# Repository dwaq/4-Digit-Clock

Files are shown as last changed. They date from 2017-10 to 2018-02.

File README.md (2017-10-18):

# 4-Digit-Clock
CNC fab-able clock based on the ATMEGA328P

## Hardware
Schematic and Board files created in Autodesk EAGLE 8.

## Software
Software written in Arduino.

Past software was written in C, but had a fatal bug. It was deleted in [commit 8a6b835](https://github.com/dwaq/4-Digit-Clock/commit/8a6b8354e79f4e0a9605a9b12ea75d16f3cf73cc).

## License
This work is licensed under a Creative Commons Attribution 3.0 Unported License.

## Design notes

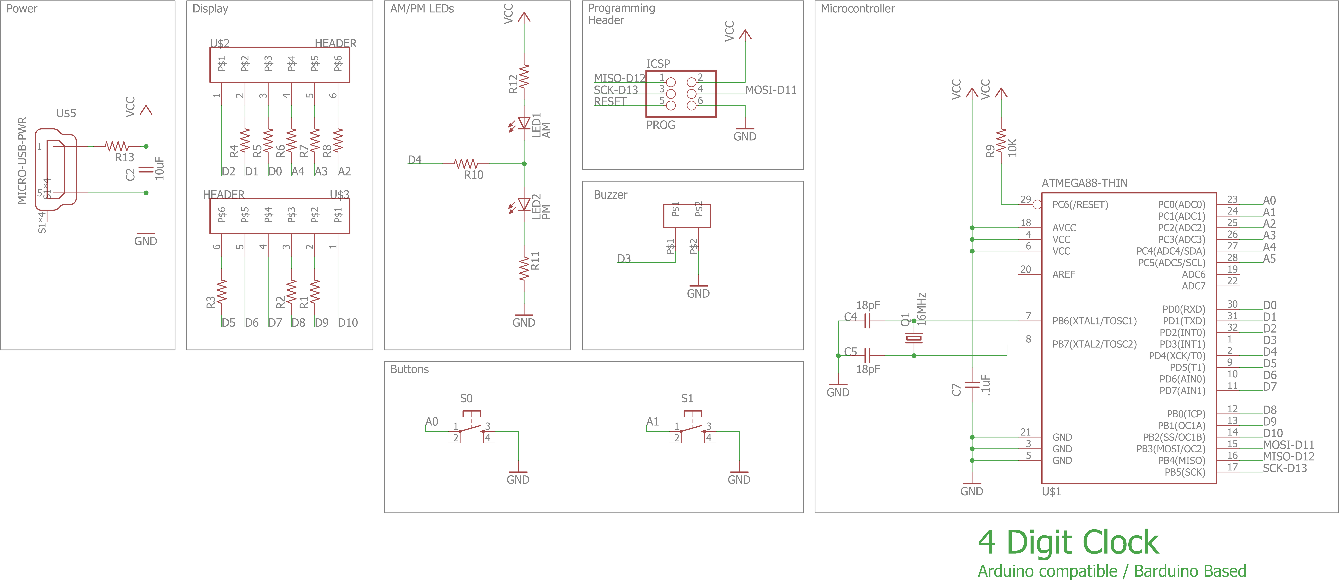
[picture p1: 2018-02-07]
schematic.png

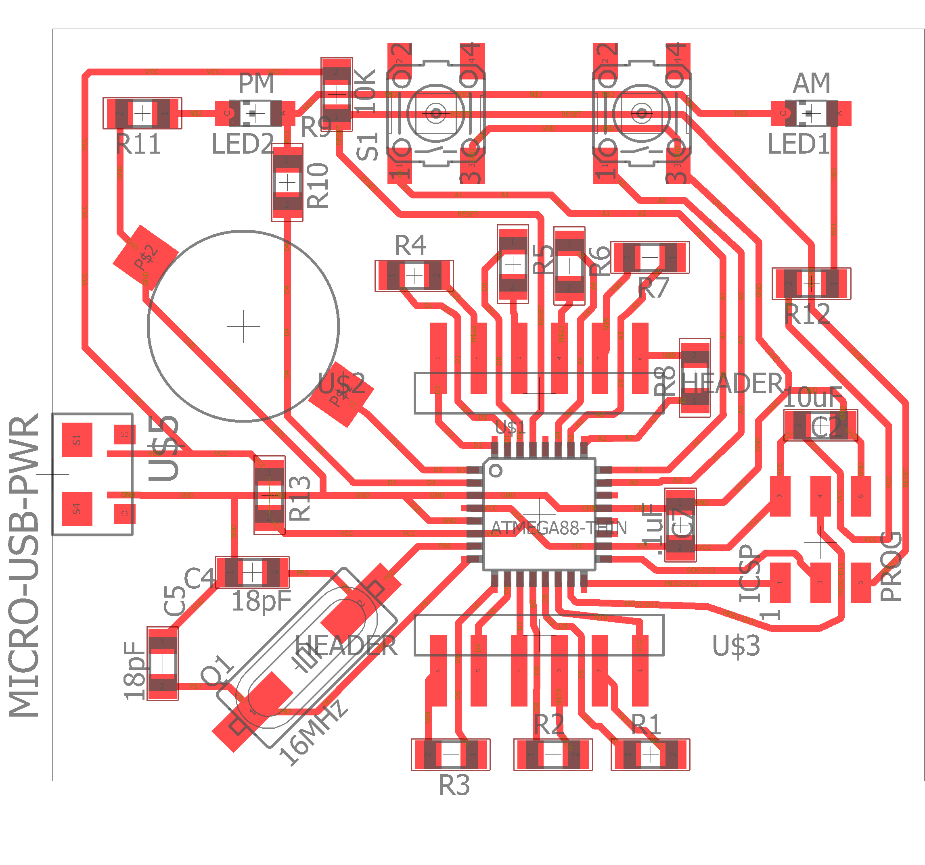
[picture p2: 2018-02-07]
layout.png

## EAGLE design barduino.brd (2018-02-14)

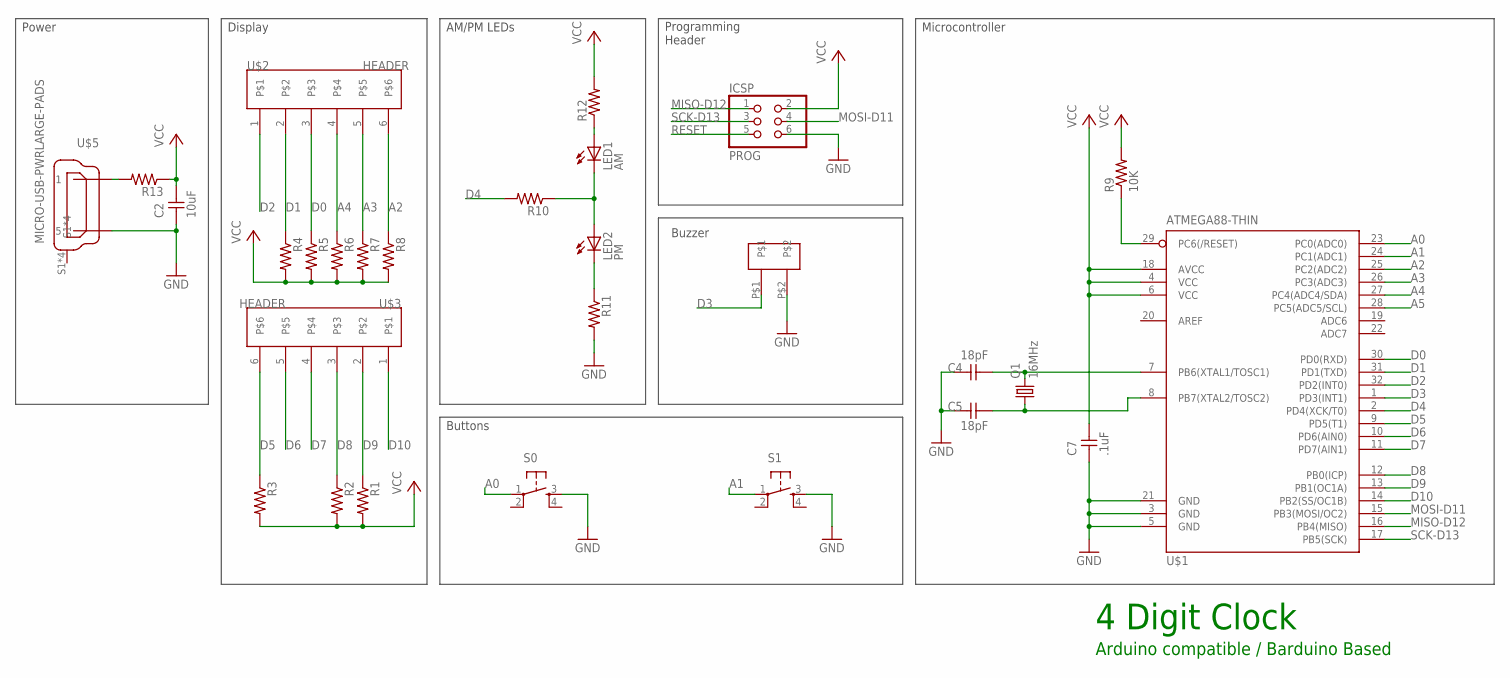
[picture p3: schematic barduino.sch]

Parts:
C2: 10uF; 1206
C4, C5: 18pF; 1206
C7: .1uF; 1206
ICSP: PROG; 2X03SMD
LED1: AM; CHIPLED_1206
LED2: PM; CHIPLED_1206
Q1: 16MHz; HC49UP
R1, R2, R3, R4, R5, R6, R7, R8, R10, R11, R12, R13: R-US_R1206; R1206
R9: 10K; 1206
S0, S1: 6MM_SWITCH6MM_SWITCH; 6MM_SWITCH
U$1: ATMEGA88-THIN; TQFP32-08THIN
U$2, U$3: HEADER
U$4: BUZZERLARGE-PADS; CD-1206-SMT-LRG
U$5: MICRO-USB-PWRLARGE-PADS; DX4R005HJ5-PWR-PADS

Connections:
A0: S0.1, U$1.23 (PC0(ADC0))
A1: S1.1, U$1.24 (PC1(ADC1))
A2: R8.1, U$1.25 (PC2(ADC2)), U$2.6
A3: R7.1, U$1.26 (PC3(ADC3)), U$2.5
A4: R6.1, U$1.27 (PC4(ADC4/SDA)), U$2.4
A5: U$1.28 (PC5(ADC5/SCL))
D0: R5.1, U$1.30 (PD0(RXD)), U$2.3
D1: R4.1, U$1.31 (PD1(TXD)), U$2.2
D2: U$1.32 (PD2(INT0)), U$2.1
D3: U$1.1 (PD3(INT1)), U$4.P$1
D4: R10.2, U$1.2 (PD4(XCK/T0))
D5: R3.1, U$1.9 (PD5(T1)), U$3.6
D6: U$1.10 (PD6(AIN0)), U$3.5
D7: U$1.11 (PD7(AIN1)), U$3.4
D8: R2.1, U$1.12 (PB0(ICP)), U$3.3
D9: R1.1, U$1.13 (PB1(OC1A)), U$3.2
D10: U$1.14 (PB2(SS/OC1B)), U$3.1
GND: C2.1, C4.1, C5.1, C7.1, ICSP.6, R11.2, S0.3 (S), S1.3 (S), U$1.3 (GND), U$1.5 (GND), U$1.21 (GND), U$4.P$2, U$5.GND (5)
MISO-D12: ICSP.1, U$1.16 (PB4(MISO))
MOSI-D11: ICSP.4, U$1.15 (PB3(MOSI/OC2))
unnamed: LED1.A, R12.1
unnamed: LED2.C, R11.1
unnamed: LED1.C, LED2.A, R10.1
PB6: C4.2, Q1.2, U$1.7 (PB6(XTAL1/TOSC1))
PB7: C5.2, Q1.1, U$1.8 (PB7(XTAL2/TOSC2))
RESET: ICSP.5, R9.1, U$1.29 (PC6(/RESET))
SCK-D13: ICSP.3, U$1.17 (PB5(SCK))
VCC: C2.2, C7.2, ICSP.2, R1.2, R2.2, R3.2, R4.2, R5.2, R6.2, R7.2, R8.2, R9.2, R12.2, R13.1, R13.2, U$1.4 (VCC), U$1.6 (VCC), U$1.18 (AVCC), U$5.VBUS (1)

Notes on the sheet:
Power
Buttons
Programming Header
4 Digit Clock
Arduino compatible / Barduino Based
Buzzer
Display
AM/PM LEDs
Microcontroller

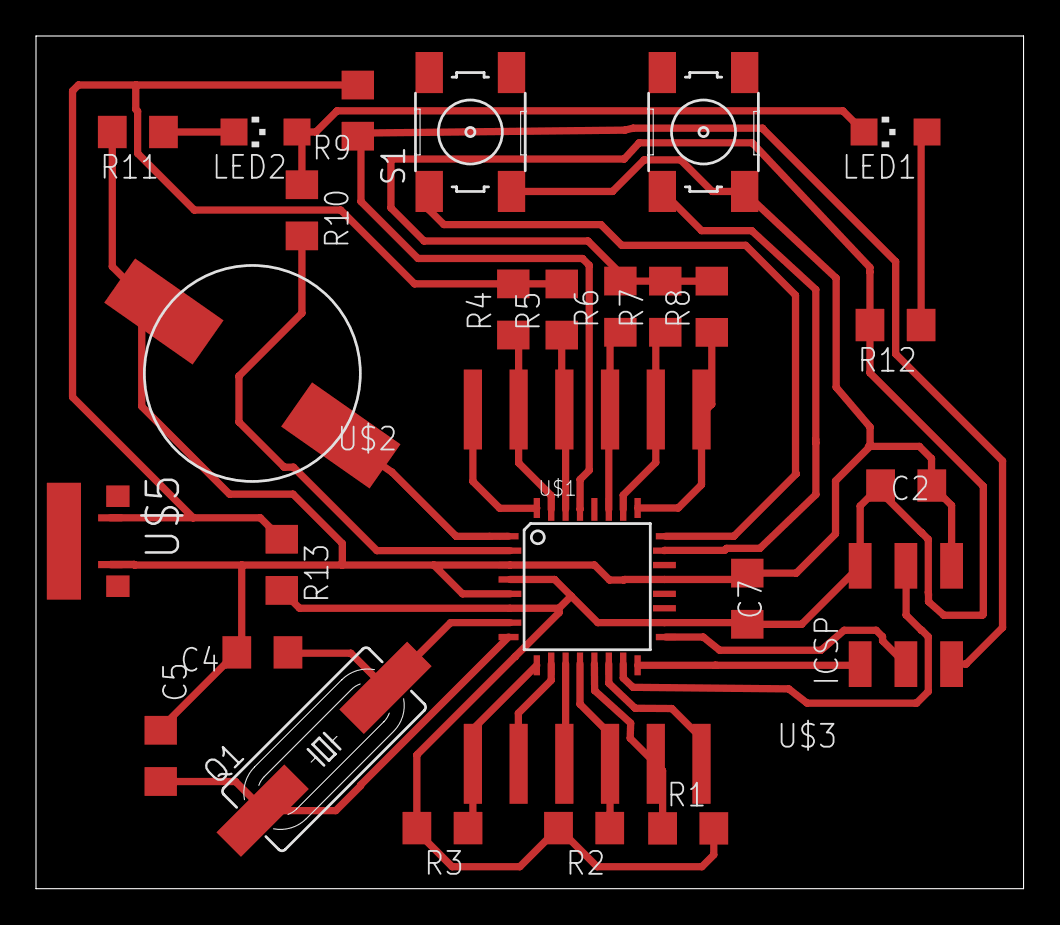
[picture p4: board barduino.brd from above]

Board: 2 copper layers, 54.9 x 47.4 mm, 28 parts (0 on the bottom side), 27 nets.

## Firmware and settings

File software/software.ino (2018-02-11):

#include "main.h"
#include "display.h"
#include <TimerOne.h>

// time
struct TimeType {
  int sec;
  int min;
  int hr;
  // differentiate between AM and PM
  // 0 = AM // 1 = PM
  int time_of_day;
  // decimal point
  int dp;
  // switch between HH:MM and MM:SS
  int display;
};
TimeType time;

// alarm
struct AlarmType {
  // alarm on or off
  int enabled;
  // alarm time
  int hr;
  int min;
  // AM/PM for alarm
  // 0 = AM // 1 = PM
  int time_of_day;
  // alarm going off
  int play;
};
AlarmType alarm;

// default to clock display mode
int settings_mode = CLOCK;

// hourly chime on or off
int hr_chime_enabled = 1;

// capture only 1 button press (kinda like debouncing)
int buttonBlockA0 = 0;
int buttonBlockA1 = 0;

void setup() {
  // set up default time values
  time.sec = 0;
  time.min = 0;
  time.hr = 12;
  time.time_of_day = 1;
  time.dp = 0;
  time.display = 1;

  // set up default alarm values
  alarm.hr = 12;
  alarm.min = 0;
  alarm.time_of_day = 1;
  alarm.enabled = 0;
  alarm.play = 0;

  // set display pins to outputs
  displaySetup();

  // set LED pin to output
  ledSetup();

  // start at PM
  ledPm();

  // set button pins to interrupt-enabled inputs
  buttonsSetup();

  // setup timer for 1 second tick
  Timer1.initialize(1000000);
  Timer1.attachInterrupt(increaseSecond);
}

void loop() {
  // displayDigits in loop so they keep updating

  // default clock display mode
  if (settings_mode == CLOCK)
  {
    // HH:MM
    if(time.display)
    {
      // don't display leading 0 for hours
      // display 2:00 instead of 02:00
      if (time.hr < 10)
      {
        displayDigits(BLANK, time.hr%10, time.dp, time.min/10, time.min%10);
      }
      else
      {
        displayDigits(time.hr/10, time.hr%10, time.dp, time.min/10, time.min%10);
      }
    }
    // MM:SS
    else
    {
      displayDigits(time.min/10, time.min%10, time.dp, time.sec/10, time.sec%10);
    }
  }
  else if (settings_mode == SET_HR)
  {
    displayDigits(SET_HR, BLANK, BLANK, time.hr/10, time.hr%10);
  }
  else if (settings_mode == SET_MIN)
  {
    displayDigits(SET_MIN, BLANK, BLANK, time.min/10, time.min%10);
  }
  else if (settings_mode == SET_CHIME)
  {
    // on
    if (hr_chime_enabled)
    {
      displayDigits(SET_CHIME, BLANK, BLANK, 0, N);
    }
    // off
    else
    {
      displayDigits(SET_CHIME, 0, BLANK, 0xF, 0xF);
    }
  }
  else if (settings_mode == SET_ALARM)
  {
    // on
    if (alarm.enabled)
    {
      displayDigits(SET_ALARM, BLANK, BLANK, 0, N);
    }
    // off
    else
    {
      displayDigits(SET_ALARM, 0, BLANK, 0xF, 0xF);
    }
  }
  else if (settings_mode == SET_ALARM_HR)
  {
    displayDigits(SET_ALARM_HR, BLANK, BLANK, alarm.hr/10, alarm.hr%10);
    
    // change LED to match alarm
    if (alarm.time_of_day)
    {
      ledPm();
    }
    else{
      ledAm();
    }
  }
  else if (settings_mode == SET_ALARM_MIN)
  {
    displayDigits(SET_ALARM_MIN, BLANK, BLANK, alarm.min/10, alarm.min%10);
    
    // change LED to match time
    // (back to normal behavior after setting LED to alarm time of day in last state)
    if (time.time_of_day)
    {
      ledPm();
    }
    else{
      ledAm();
    }
  }

  // S1 button pressed in interrupt
  if (buttonBlockA0 == 10)
  {
    // reduce so it doesn't get caught in a loop
    buttonBlockA0--;
    // S1 handler
    buttonS1();
  }

  // S2 button pressed in interrupt
  if (buttonBlockA1 == 10)
  {
    // reduce so it doesn't get caught in a loop
    buttonBlockA1--;
    // S2 handler
    buttonS2();
  }
}

// correctly move through settings states
void nextSettingState(void)
{
  // if you've turned alarm off, dont't set it, go back to clock display
  if ((settings_mode == SET_ALARM) & (alarm.enabled == 0))
  {
    settings_mode = CLOCK;
  }
  // last setting, go back to clock display
  else if (settings_mode == SET_ALARM_MIN)
  {
    settings_mode = CLOCK;
  }
  // else just go to next state
  else{
    settings_mode++;
  }

  // stop counting time when you're trying to set it
  if (settings_mode == SET_HR)
  {
    // disable timer counter
    Timer1.stop();

    // also reset seconds for good measure
    time.sec = 0;
  }
  // start counting after you've set the time
  else if (settings_mode == SET_CHIME)
  {
    // restart timer counter
    Timer1.restart();
  }
}

// Hack to get pin change interrupts on analog pins
// http://www.geertlangereis.nl/Electronics/Pin_Change_Interrupts/PinChange_en.html
void buttonsSetup()
{
  // set button pins as inputs with internal pull-ups enabled
  pinMode(A0, INPUT);
  digitalWrite(A0, HIGH);
  pinMode(A1, INPUT);
  digitalWrite(A1, HIGH);

  // switch interrupts off while messing with their settings
  cli();
  // Enable PCINT1 interrupt
  PCICR =0x02;
  PCMSK1 = 0b00000111;
  // turn interrupts back on
  sei();
}

// Interrupt service routine for every analog pin change
// A0, A1, A2, A3, A4, A5
ISR(PCINT1_vect) {
  // press A0
  if (digitalRead(A0)==0 && buttonBlockA0==0)
  {
    // pressing button stops alarm
    if (alarm.play == 1)
    {
      noTone(3);
      alarm.play = 0;

      // set to a smaller value so bouncing dones't trigger interrupt
      buttonBlockA0 = 9;
    }
    // else do normal behavior
    else {
      // set to 10
      buttonBlockA0 = 10;
      
      // will handle press in main loop
    }
  }
  // release A0
  if (digitalRead(A0)==1)
  {
    // count down after releasing
    if (buttonBlockA0 > 0)
    {
      buttonBlockA0--;
    }
  }

  // press A1
  if (digitalRead(A1)==0 && buttonBlockA1==0)
  {
    // pressing button stops alarm
    if (alarm.play == 1)
    {
      noTone(3);
      alarm.play = 0;

      // set to a smaller value so bouncing doesn't trigger interrupt
      buttonBlockA1 = 9;
    }
    // else do normal behavior
    else
    {
      // set to 10
      buttonBlockA1 = 10;
      
      // will handle press in main loop
    }
  }
  // release A1
  if (digitalRead(A1)==1)
  {
    // count down after releasing
    if (buttonBlockA1 > 0)
    {
      buttonBlockA1--;
    }
  }
}

void buttonBuzzer()
{
  // send 133 frequency tone for 70 ms to pin 3
  tone(3, 133, 70);
  // wait 70ms for tone to finish
  delay(70);
  // in case it didn't finish, kill it
  noTone(3);
}

void buttonS1()
{
  // play tone
  buttonBuzzer();
  
  // go to next settings state
  nextSettingState();
}

void buttonS2()
{
  // play tone
  buttonBuzzer();
  
  // need to be in clock display mode to change these settings
  if (settings_mode == CLOCK)
  {
    // switch between HH:MM and MM:SS
    time.display ^= 1;
  }
  // else in some settings mode...
  else if (settings_mode == SET_HR)
  {
    increaseHour();
  }
  else if (settings_mode == SET_MIN)
  {
    if (++time.min==60)
    {
      time.min=0;
    }
  }
  else if (settings_mode == SET_CHIME)
  {
    // switch between hourly chime enabled and disabled
    hr_chime_enabled ^= 1;
  }
  else if (settings_mode == SET_ALARM)
  {
    // switch between alarm enabled and disabled
    alarm.enabled ^= 1;
  }
  else if (settings_mode == SET_ALARM_HR)
  {
    // switch time of day when transitioning from 11 to 12
    if (++alarm.hr==12)
    {
      // flip between AM and PM
      alarm.time_of_day ^= 1;
    }
  
    if (alarm.hr==13)
    {
      alarm.hr=1;
    }
  }
  else if (settings_mode == SET_ALARM_MIN)
  {
    if (++alarm.min==60)
    {
      alarm.min=1;
    }
  }
}

// action to be done every 1 sec
void increaseSecond()
{
  // increase seconds
  if (++time.sec==60)
  {
    time.sec=0;
    // increase minute every 60 seconds
    if (++time.min==60)
    {
      time.min=0;
      // increase hour every 60 seconds
      increaseHour();
    }

    // Check if the alarm should sound
    // go in small steps so less processing if it shouldn't
    
    // check if enabled
    if (alarm.enabled)
    {
      // check if correct time of day
      if (alarm.time_of_day ==  time.time_of_day)
      {
        // check if correct hour
        if (alarm.hr == time.hr)
        {
          // check if correct minute
          if (alarm.min == time.min)
          {
            // would only get here when second == 0, so don't need to check that
      
            // play a tone for a minute
            tone(3, 133, 60000);
            // it'll turn off after a minute, but will still require a button press
            // to get out of this mode
            // not worth adding another check for this

            // set a flag so we can turn off alarm
            alarm.play = 1;
          }
        }
      }
    }
  }
  
  // flip decimal point every second
  time.dp ^= 1;
}

// increase hour by 1 and handle AM/PM
void increaseHour(void)
{
  // play chime on the hour if enabled
  // and it's in clock mode (not setting time)
  if (hr_chime_enabled && (settings_mode == CLOCK))
  {
    // send 133 frequency tone for 333 ms to pin 3
    tone(3, 133, 333);
  }

  // switch time of day when transitioning from 11 to 12
  if (++time.hr==12)
  {
    // flip between AM and PM
    time.time_of_day ^= 1;

    // change LED to match
    if (time.time_of_day)
    {
      ledPm();
    }
    else{
      ledAm();
    }
  }

  if (time.hr==13)
  {
    time.hr=1;
  }
}

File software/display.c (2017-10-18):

#include "display.h"
#include "main.h"
#include <wiring_private.h>

// AM/PM LED is on D4 PD4
void ledSetup(void)
{
  DDRD |= (1<<DDD4);
}

// low is AM
void ledAm(void)
{
  PORTD |= (1<<PORTD4);
}

// high is PM
void ledPm(void)
{
  PORTD &= ~(1<<PORTD4);
}

// pinouts for common cathode 7 segment LED display:

// segment is active high
// segment | display | header | mcu
// A  11 D9  PB1
// B  7  D5  PD5
// C  4  D0  PD0
// D  2  A3  PC3
// E  1  A2  PC2
// F  10 D8  PB0
// G  5  D1  PD1
// DP 3  A4  PC4

// digit is active low
// digit | display | header | mcu
// 1  12 D10 PB2
// 2  9  D7  PD7
// 3  8  D6  PD6
// 4  6  D2  PD2

// set display pins to outputs
void displaySetup()
{
  DDRB |= (1<<DDB1 | 1<<DDB0 | 1<<DDB2); // A F 1
  DDRC |= (1<<DDC3 | 1<<DDC2 | 1<<DDC4); // D E DP
  DDRD |= (1<<DDD5 | 1<<DDD0 | 1<<DDD1 | 1<<DDD7 | 1<<DDD6 | 1<<DDD2); // B C G 2 3 4
}

// cycle through and display each digit
// dp is for decimal point: 0 for off; 1 for on
void displayDigits(int dig1, int dig2, int dp, int dig3, int dig4)
{
  setDigit(1, dig1);
  setDigit(2, dig2);
  setDigit(3, dig3);
  setDigit(4, dig4);
  if (dp)
  {
    // display decimal point (special parameter)
    setDigit(2, DP_ON);
  }
  else
  {
    // dont't display decimal point (special parameter)
    setDigit(2, BLANK);
  }

}

// display a number on the selected digit 1, 2, 3, or 4
void setDigit(int digit, int number)
{
  // turn all digits off
  PORTB |= (1<<PORTB2); // 1
  PORTD |= (1<<PORTD7 | 1<<PORTD6 | 1<<PORTD2); // 2 3 4

  // set up segments while digits off,
  // so that the full digit comes up simultanously
  // (although who is going to be able to detect a couple clk cycles?)
  setSegment(number);

  // then turn on specfic digit
  switch(digit)
  {
    case 1:
    // TODO: ONLY when display hours,
    // don't display leading 0
    //if (number != 0)
    //{
        PORTB &= ~(1<<PORTB2); // 1
    //}
      break;
    // this case also handles decimal point
    case 2:
      PORTD &= ~(1<<PORTD7); // 2
      break;
    case 3:
      PORTD &= ~(1<<PORTD6); // 3
      break;
    case 4:
      PORTD &= ~(1<<PORTD2); // 4
      break;
    //default:
      // bad - should't be here
  }
}

// display a number or symbol using the 7 segments
// number can be between 0-9 or settings screen uses A-F
void setSegment(int number)
{
  // first, reset all segments
  PORTB &= ~(1<<PORTB1 | 1<<PORTB0); // A F
  PORTC &= ~(1<<PORTC4 | 1<<PORTC3 | 1<<PORTC2); // DP D E
  PORTD &= ~(1<<PORTD5 | 1<<PORTD0 | 1<<PORTD1); // B C G

  // then set the coorespoding segments
  switch(number)
  {
    case 0:
      // A B C D E F
      PORTB |= (1<<PORTB1 | 1<<PORTB0); // A F
      PORTC |= (1<<PORTC3 | 1<<PORTC2); // D E
      PORTD |= (1<<PORTD5 | 1<<PORTD0); // B C
      break;
    case 1:
      // B C
      PORTD |= (1<<PORTD5 | 1<<PORTD0); // B C
      break;
    case 2:
      // A B D E G
      PORTB |= (1<<PORTB1); // A
      PORTC |= (1<<PORTC3 | 1<<PORTC2); // D E
      PORTD |= (1<<PORTD5 | 1<<PORTD1); // B G
      break;
    case 3:
      // A B C D G
      PORTB |= (1<<PORTB1); // A
      PORTC |= (1<<PORTC3); // D E
      PORTD |= (1<<PORTD5 | 1<<PORTD0 | 1<<PORTD1); // B C G
      break;
    case 4:
      // B C F G
      PORTB |= (1<<PORTB0); // F
      PORTD |= (1<<PORTD5 | 1<<PORTD0 | 1<<PORTD1); // B C G
      break;
    case 5:
      // A C D F G
      PORTB |= (1<<PORTB1 | 1<<PORTB0); // A F
      PORTC |= (1<<PORTC3); // D
      PORTD |= (1<<PORTD0 | 1<<PORTD1); // C G
      break;
    case 6:
      // A C D E F G
      PORTB |= (1<<PORTB1 | 1<<PORTB0); // A F
      PORTC |= (1<<PORTC3 | 1<<PORTC2); // D E
      PORTD |= (1<<PORTD0 | 1<<PORTD1); // C G
      break;
    case 7:
      // A B C
      PORTB |= (1<<PORTB1); // A
      PORTD |= (1<<PORTD5 | 1<<PORTD0); // B C
      break;
    case 8:
      // A B C D E F G
      PORTB |= (1<<PORTB1 | 1<<PORTB0); // A F
      PORTC |= (1<<PORTC3 | 1<<PORTC2); // D E
      PORTD |= (1<<PORTD5 | 1<<PORTD0 | 1<<PORTD1); // B C G
      break;
    case 9:
      // A B C D F G
      PORTB |= (1<<PORTB1 | 1<<PORTB0); // A F
      PORTC |= (1<<PORTC3); // D
      PORTD |= (1<<PORTD5 | 1<<PORTD0 | 1<<PORTD1); // B C G
      break;
    case 0xA:
      // A B C E F G
      PORTB |= (1<<PORTB1 | 1<<PORTB0); // A F
      PORTC |= (1<<PORTC2); // E
      PORTD |= (1<<PORTD5 | 1<<PORTD0 | 1<<PORTD1); // B C G
      break;
    case 0xB:
      // A B C D E F G
      PORTB |= (1<<PORTB1 | 1<<PORTB0); // A F
      PORTC |= (1<<PORTC3 | 1<<PORTC2); // D E
      PORTD |= (1<<PORTD5 | 1<<PORTD0 | 1<<PORTD1); // B C G
      break;
    case 0xC:
      // A D E F
      PORTB |= (1<<PORTB1 | 1<<PORTB0); // A F
      PORTC |= (1<<PORTC3 | 1<<PORTC2); // D E
      break;
    case 0xD:
      // A B C D E F
      PORTB |= (1<<PORTB1 | 1<<PORTB0); // A F
      PORTC |= (1<<PORTC3 | 1<<PORTC2); // D E
      PORTD |= (1<<PORTD5 | 1<<PORTD0); // B C
      break;
    case 0xE:
      // A D E F G
      PORTB |= (1<<PORTB1 | 1<<PORTB0); // A F
      PORTC |= (1<<PORTC3 | 1<<PORTC2); // D E
      PORTD |= (1<<PORTD1); // G
      break;
    case 0xF:
      // A E F G
      PORTB |= (1<<PORTB1 | 1<<PORTB0); // A F
      PORTC |= (1<<PORTC2); // E
      PORTD |= (1<<PORTD1); // G
      break;
    case N:
      // A B C E F
      PORTB |= (1<<PORTB1 | 1<<PORTB0); // A F
      PORTC |= (1<<PORTC2); // E
      PORTD |= (1<<PORTD5 | 1<<PORTD0); // B C
      break;
    case DP_ON:
      // DP
      PORTC |= (1<<PORTC4);
      break;
    //default:
      // case BLANK falls through here
      // just turns off the segment by initial "reset all segments" code
  }
}

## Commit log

2017-05-31 Based on barduino
    http://fabacademy.org/archives/content/projects/barduino/index.html
    [barduino.brd, barduino.sch]
2017-05-31 convert to new eagle format
    [barduino.brd, barduino.sch]
2017-05-31 add microbuilder library
    has through hole 4 digit display
2017-05-31 Stripped a lot and added some clock parts
    [barduino.brd, barduino.sch]
2017-05-31 Replace pwr jack with usb conn
    [barduino.brd, barduino.sch]
2017-05-31 clean up a little
    [barduino.brd, barduino.sch]
2017-05-31 remove reest button
    [barduino.brd, barduino.sch]
2017-05-31 clean up
    [barduino.brd]
2017-05-31 moving things
    [barduino.brd, barduino.sch]
2017-06-01 replace clock part with 2 custom headers
    [barduino.brd, barduino.sch]
2017-06-01 display and buttons connected
    [barduino.brd, barduino.sch]
2017-06-01 lots of routing
    [barduino.brd, barduino.sch]
2017-06-01 some changes before moving the USB conn
    [barduino.brd]
2017-06-01 USB move is going well
    [barduino.brd, barduino.sch]
2017-06-01 board fully laid out
    [barduino.brd, barduino.sch]
2017-06-01 remove crossover resistor
    [barduino.brd, barduino.sch]
2017-06-01 remove VCC resistor
    [barduino.brd, barduino.sch]
2017-06-01 create buzzer surface mount footprint
2017-06-01 put new buzzer on board
    [barduino.brd, barduino.sch]
2017-06-01 move buttons to top
    [barduino.brd]
2017-06-01 bring in board outline
    [barduino.brd]
2017-06-01 mirror header to match pcb layout
    [barduino.sch]
2017-06-01 add current limiting resistors to the 4 digits
    [barduino.brd, barduino.sch]
2017-06-01 connect some missing wires
    [barduino.brd]
2017-08-02 generated gerbers
    [barduino.GBL, barduino.GBO, barduino.GBS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]
2017-08-02 reset pullup resistor should be 10k
    [barduino.brd, barduino.sch]
2017-08-02 add switch statement to segment
2017-08-02 remove default case since it's not used
2017-08-02 starter code to reset and set all segments
    [display.c]
2017-08-02 should write segments correctly
    [display.c]
2017-08-02 typo on pin for G segment
2017-08-13 new timer method for accurate 1sec
2017-08-13 proper function prototype
2017-08-15 had digit logic inverted
    [display.c]
2017-08-15 set decimal point correctly
    [display.c]
2017-08-16 move 1 sec timer init into new function
2017-08-16 add button setup code
2017-08-16 add pin change interrupt handler
2017-08-17 fix and generalize comments
    [display.c]
2017-08-17 handle S2 button presses in settings
2017-08-17 add new 1206 AM and PM LEDs
    [barduino.brd, barduino.sch]
2017-08-17 add border around schematic and values
    [barduino.brd, barduino.sch]
2017-08-17 eagle switched names of temp files
2017-08-17 add am/pm led code
2017-10-08 use TimerOne library instead of timer registers
2017-10-08 use Arduino-style button interrupts
2017-10-08 disable/restart timer when setting time
2017-10-08 add deboucing to buttons
2017-10-08 play tone on button press
2017-10-12 Add resistors to segments, not digits
    1. Renamed reset and AM/PM LED R's
    2. Fixed error on LED net
    3. Moved/added resistors to all 8 segments
    4. Updated eagle
    [barduino.sch]
2017-10-12 attached resistors
    need to fix buttons and reset
    [barduino.brd]
2017-10-12 ugly but everything connected
    [barduino.brd]
2017-10-12 made the routing pretty(ier)
    [barduino.brd]
2017-10-12 make a new mini USB connector that doesn't have data lines since they're not used
2017-10-12 Put new USB power connector on sch/brd
    [barduino.brd, barduino.sch]
2017-10-12 Buttons don't have a value
    [barduino.brd, barduino.sch]
2017-10-16 replace thru hole (mistake) with surface mount USB connector
    [barduino.brd, barduino.sch]
2017-10-16 remove thru hole part from library
2017-10-16 Explain that TimerOne library needs installed
2017-10-17 update sch to correctly light AM/PM LEDs
    [barduino.brd, barduino.sch]
2017-10-17 start new AM/PM LED layout
    [barduino.brd]
2017-10-17 align schematic, add another resistor
    [barduino.brd, barduino.sch]
2017-10-17 fixed mistake on LEDs net
    [barduino.brd, barduino.sch]
2017-10-18 change variable name so it doesn't interfer with arduino library
2017-10-18 remind myself about alarm am/pm led
2017-10-18 rename and move Arduino software files
2017-10-20 move button tone into new function
2017-10-20 handle button presses in main loop instead of interrupts
2017-10-20 in alarm hr setting, use LED to display time of day
2017-10-20 pressing any button stops alarm
2018-01-15 add pin names, outline, text
2018-01-15 create and connect device
2018-01-15 replace mini usb connector with micro usb
    [barduino.brd, barduino.sch]
2018-01-15 connect usb micro connector with jumper
    also reduces the board size
    [barduino.brd, barduino.sch]
2018-01-15 remove small traces inside microcontroller
    [barduino.brd]
2018-01-15 use specific footprint for buzzer
2018-01-15 replace crystal with new footprint part
    [barduino.brd, barduino.sch]
2018-01-15 move crystal into place
    [barduino.brd]
2018-01-15 rip up some wires
    [barduino.brd]
2018-01-15 go back to original board size
    [barduino.brd]
2018-01-15 connected most signals
    still some air wires left
    [barduino.brd]
2018-01-15 connected RESET
    [barduino.brd]
2018-01-15 only a couple air wires left
    [barduino.brd]
2018-01-15 finally fixed that buzzer connection
    [barduino.brd]
2018-01-15 ignore airwire on jumper
    [barduino.brd]
2018-01-16 Reroute some signals so it can actually be built
    [barduino.brd]
2018-01-16 fix ERC errors
    [barduino.brd]
2018-01-16 fix air wires
    [barduino.brd]
2018-02-07 add image of schematic, ok
2018-02-11 alarm code was in the wrong section
    [software.ino]
2018-02-11 add pull ups on display resistors
    [barduino.brd, barduino.sch]
2018-02-11 new buzzer footprint with larger pads
2018-02-11 new USB footprint with single, large pad
2018-02-14 change to new USB and buzzer footprint on schematic and layout
    [barduino.brd, barduino.sch]
